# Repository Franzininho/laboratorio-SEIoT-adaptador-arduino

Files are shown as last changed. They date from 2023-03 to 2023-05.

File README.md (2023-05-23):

## Adaptador para Arduino - Placa Laboratório de Sistemas Embarcados e IoT

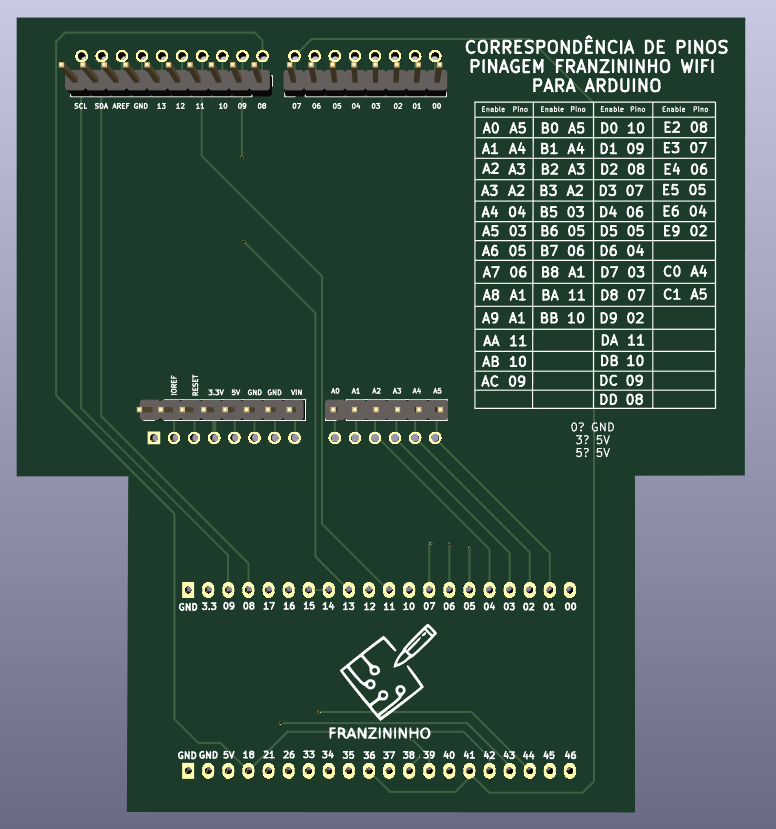
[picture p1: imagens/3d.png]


## O que é este projeto?

Este projeto é um adaptador que permite a conexão da placa Arduino Uno com a placa [Laboratório de Sistemas Embarcados e IoT](https://github.com/Franzininho/laboratorio-SEIoT-Franzininho-Wifi) através de uma correspondência entre os pinos do Arduino Uno e a pinagem da Franzininho Wifi (placa utilizada no projeto da placa de laboratório). Para utilizar o adaptador basta conectá-lo ao Arduino como um shield e então conectar o adaptador na placa. 

Esse projeto está sob a licença [CERN-OHL-S v2](https://ohwr.org/cern_ohl_s_v2.txt)

## Codificação dos pinos de ativação

Como a placa [Laboratório de Sistemas Embarcados e IoT](https://github.com/Franzininho/laboratorio-SEIoT-Franzininho-Wifi) conta com um sistema de codificação dos pinos de ativação dos periféricos, foi preciso codificar esses pinos. A codificação escolhida tem dois algarismos sendo que o primeiro indica a funcionalidade do pino e o segundo indica uma numeração do pino.

O código de cada pino está impresso ao lado dele na placa principal e para facilitar a utilização do adaptador foi impresso nele a correspondência entre o pino do Arduino e o código de ativação na placa. Essa correspondência também pode ser acessada [clicando aqui](./informacoes/mapeamento.md).

Além disso, também foi desenvolvida uma biblioteca para uso em conjunto com o placa que permite o uso dos códigos dos pinos de ativação dentro da programação. [Clique aqui](https://github.com/Franzininho/biblioteca-laboratorioFW_ARDUNO) para acessar a **biblioteca laboratorioFW_ARDUNO.**

## Como o projeto foi desenvolvido?

O projeto foi desenvolvido com o software [KiCad 7](https://www.kicad.org/). Esse software é aberto e está disponível para Linux, MacOS e Windows.

## Certificação OSHWA
(https://certification.oshwa.org/br000013.html)

[Clique aqui](https://certification.oshwa.org/br000013.html) para acessar

---

#### Feito por [LelePG](https://github.com/LelePG)

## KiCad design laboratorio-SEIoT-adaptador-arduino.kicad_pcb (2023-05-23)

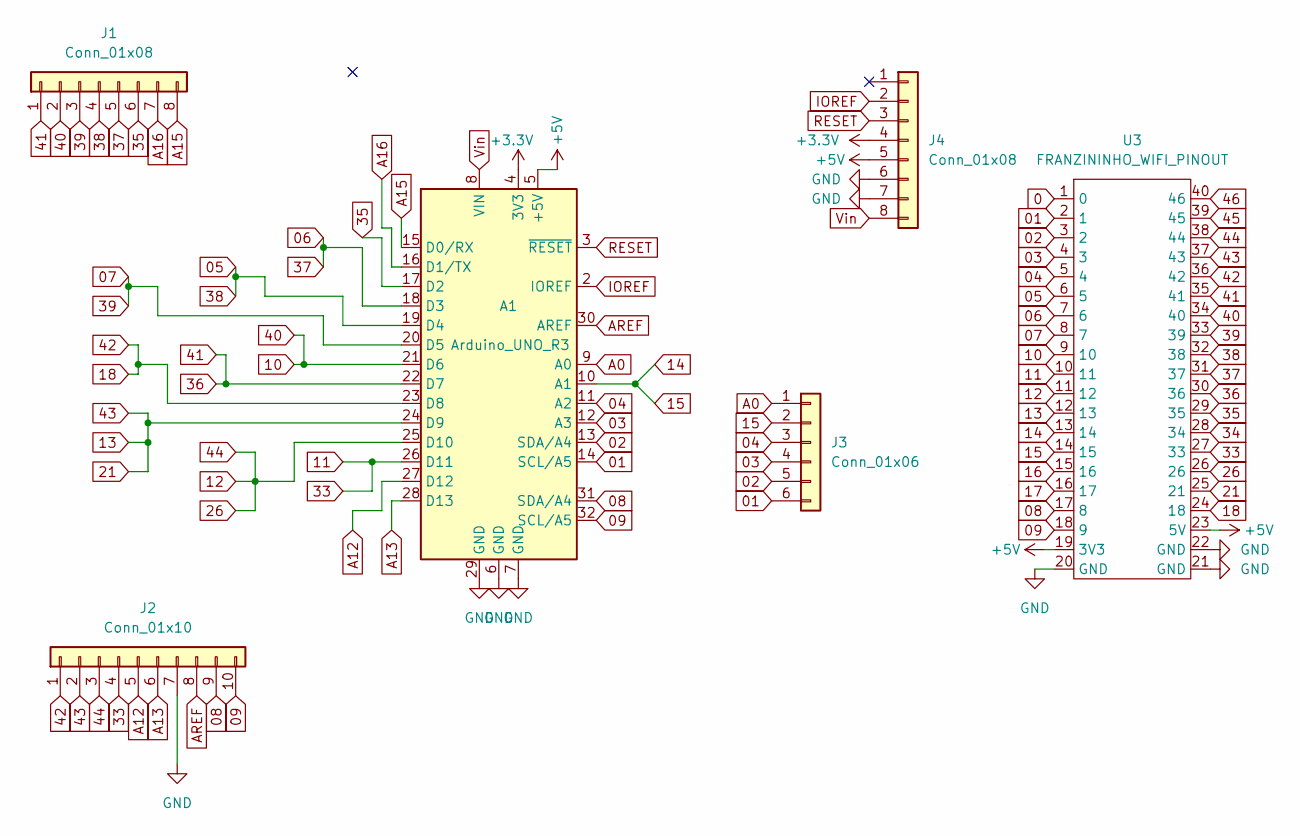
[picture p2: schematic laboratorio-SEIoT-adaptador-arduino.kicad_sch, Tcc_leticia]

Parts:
A1: Arduino_UNO_R3
J1, J4: Conn_01x08; PinHeader_1x08_P2.54mm_Vertical
J2: Conn_01x10; PinHeader_1x10_P2.54mm_Vertical
J3: Conn_01x06; PinHeader_1x06_P2.54mm_Vertical
U3: FRANZININHO_WIFI_PINOUT

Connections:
0: U3.1 (0)
01: A1.14 (SCL/A5), J3.6, U3.2 (1)
02: A1.13 (SDA/A4), J3.5, U3.3 (2)
03: A1.12 (A3), J3.4, U3.4 (3)
04: A1.11 (A2), J3.3, U3.5 (4)
05: A1.19 (D4), J1.4, U3.6 (5), U3.32 (38)
06: A1.18 (D3), J1.5, U3.7 (6), U3.31 (37)
07: A1.20 (D5), J1.3, U3.8 (7), U3.33 (39)
08: A1.31 (SDA/A4), J2.9, U3.17 (8)
09: A1.32 (SCL/A5), J2.10, U3.18 (9)
10: A1.21 (D6), J1.2, U3.9 (10), U3.34 (40)
11: A1.26 (D11), J2.4, U3.10 (11), U3.27 (33)
12: A1.25 (D10), J2.3, U3.11 (12), U3.26, U3.38 (44)
13: A1.24 (D9), J2.2, U3.12 (13), U3.25 (21), U3.37 (43)
14: A1.10 (A1), J3.2, U3.13 (14), U3.14 (15)
16: U3.15 (16)
17: U3.16 (17)
18: A1.23 (D8), J2.1, U3.24 (18), U3.36 (42)
34: U3.28 (34)
35: A1.17 (D2), J1.6, U3.29 (35)
36: A1.22 (D7), J1.1, U3.30 (36), U3.35 (41)
45: U3.39 (45)
46: U3.40 (46)
+3.3V: A1.4 (3V3), J4.4
+5V: A1.5 (+5V), J4.5, U3.19 (3V3), U3.23 (5V)
A0: A1.9 (A0), J3.1
A12: A1.27 (D12), J2.5
A13: A1.28 (D13), J2.6
A15: A1.15 (D0/RX), J1.8
A16: A1.16 (D1/TX), J1.7
AREF: A1.30 (AREF), J2.8
GND: A1.6 (GND), A1.7 (GND), A1.29 (GND), J2.7, J4.6, J4.7, U3.20 (GND), U3.21 (GND), U3.22 (GND)
IOREF: A1.2 (IOREF), J4.2
RESET: A1.3 (~RESET), J4.3
Vin: A1.8 (VIN), J4.8

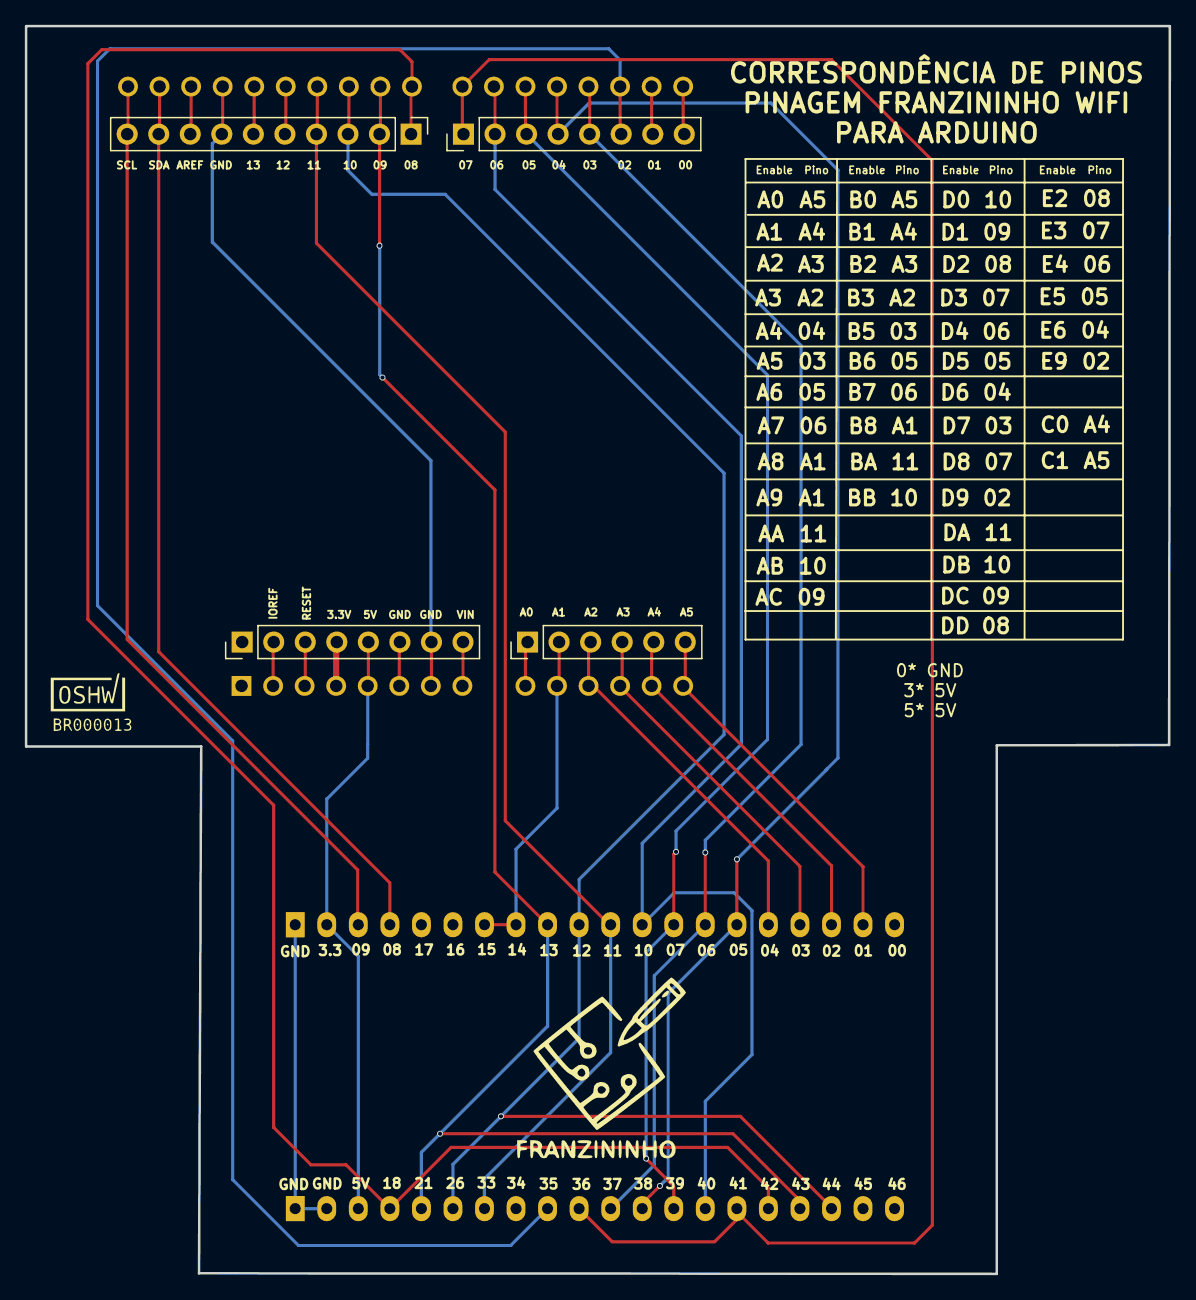
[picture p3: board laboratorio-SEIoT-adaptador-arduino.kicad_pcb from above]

Board: 2 copper layers, 92.1 x 100.5 mm, 7 parts (1 on the bottom side), 29 nets.

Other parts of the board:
G1: LOGO

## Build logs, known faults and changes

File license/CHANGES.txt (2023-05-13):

Change Format
Your name Date Description of modification

Change Log

Letícia Garcez 2023-05-12 Initial release of Laboratório de Sistemas Embarcados e IoT - Adaptador Arduino under cern_ohl_s_v2

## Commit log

2023-03-25 primeiro commit
    [franzininho_lab_adaptador_arduino.kicad_pcb, franzininho_lab_adaptador_arduino.kicad_sch]
2023-03-25 correção de nomenclatura
    [laboratorio-SEIoT-adaptador-arduino.kicad_pcb, laboratorio-SEIoT-adaptador-arduino.kicad_sch]
2023-05-13 adição de licensa
    [laboratorio-SEIoT-adaptador-arduino.kicad_pcb]
2023-05-23 adicionada certificação OSHWA
    [laboratorio-SEIoT-adaptador-arduino.kicad_pcb]

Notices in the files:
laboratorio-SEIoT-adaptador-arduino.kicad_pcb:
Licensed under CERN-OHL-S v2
